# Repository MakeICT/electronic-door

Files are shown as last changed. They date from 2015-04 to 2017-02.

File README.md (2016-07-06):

# Master Control Program 

This system is used to secure spaces with an electronic door latch.

## Dependencies:
* [Node + NPM](Node.js)
* [PostgreSQL](http://www.postgresql.org/)
* [Arduino 1.6.5](https://www.arduino.cc/)

## Hardware requirements: 
* [Server protocol RS-485](https://en.wikipedia.org/wiki/RS-485) for the server/client communication.
* [Arduino Nano](https://www.arduino.cc/) for the door client (This is required for the matching footprint).
* [NFC reader](https://www.adafruit.com/products/364). This is the one that we are using for our version of the door lock. 

Diagram of the door lock project

* * *

## Todo
* Server
	* Super admins vs group admins
	* Make plugins respect disabled mode
	* When unlocking from web ui, display user in log
	
* Client
	* New NFC reader
	* Add doorbell input (capacitive?)
	* Design/build case for front
	* Build 2nd client for testing & back door

## License 

> Copyright (C) 2014-2016 MakeICT
> 
> This program is free software: you can redistribute it and/or modify it 
> under the terms of the GNU General Public License as published by the 
> Free Software Foundation, either version 3 of the License, or (at your 
> option) any later version.
> 
> This program is distributed in the hope that it will be useful, but 
> WITHOUT ANY WARRANTY; without even the implied warranty of 
> MERCHANTABILITY or FITNESS FOR A PARTICULAR PURPOSE.  See the GNU 
> General Public License for more details.
> 
> You should have received a copy of the GNU General Public License along 
> with this program.  If not, see [The GNU licenses page](http://www.gnu.org/licenses)
    
* * *

This is a work in progress. For more information, please visit the [MakeICT Wiki](http://makeict.org/wiki/index.php/Electronic_Door_Entry).

* * *

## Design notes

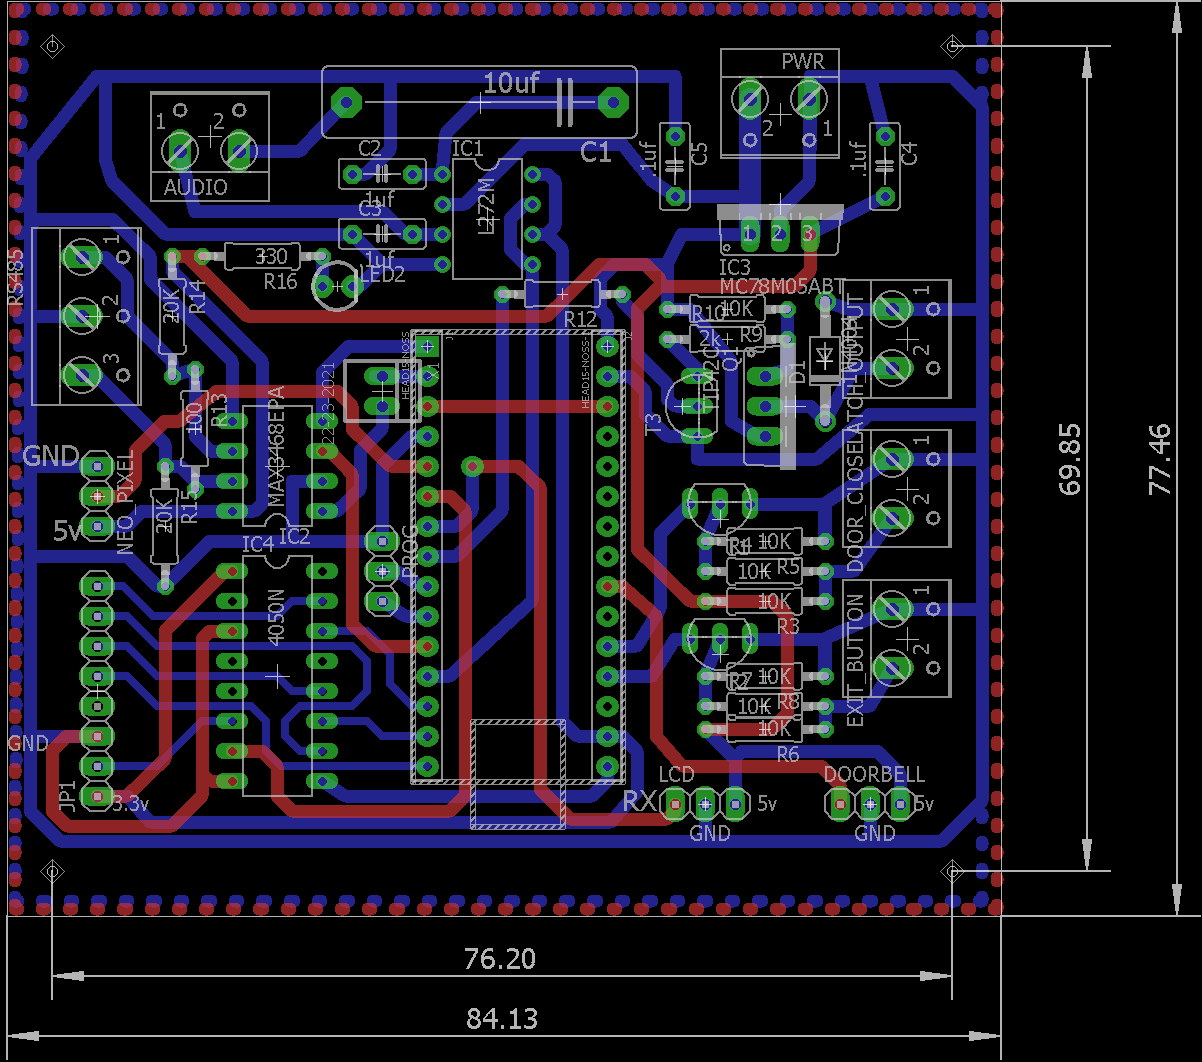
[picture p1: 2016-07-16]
door-client/hardware/doc/Door_Client_Layout_With_Dimensions.png

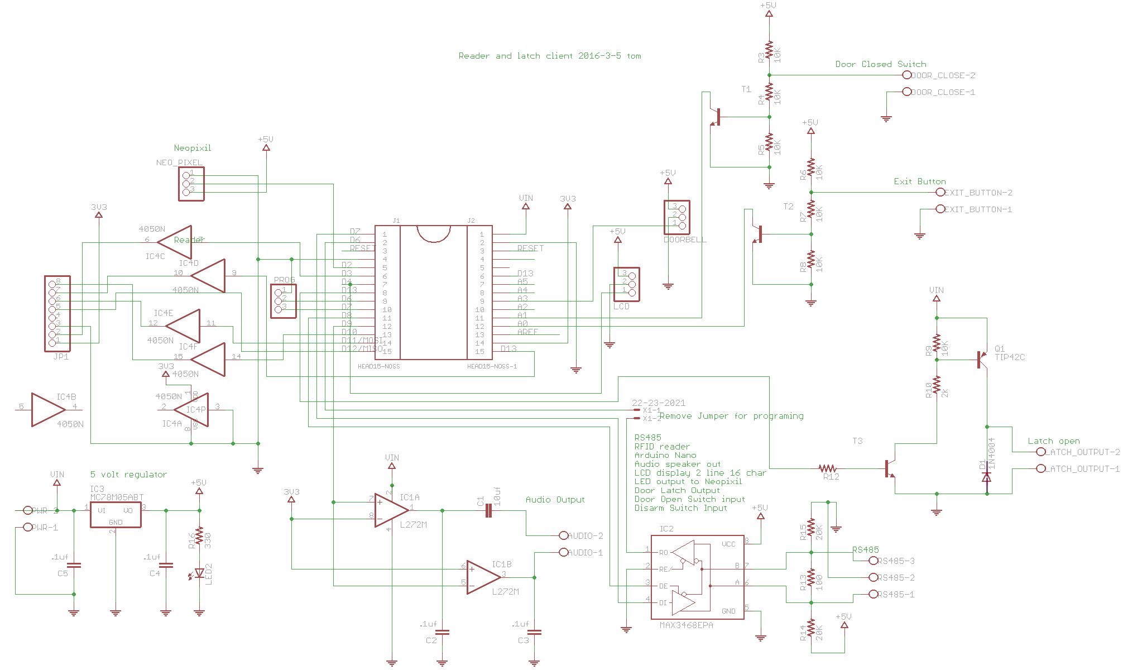
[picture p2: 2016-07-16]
door-client/hardware/doc/Door_Client_Schematic.png

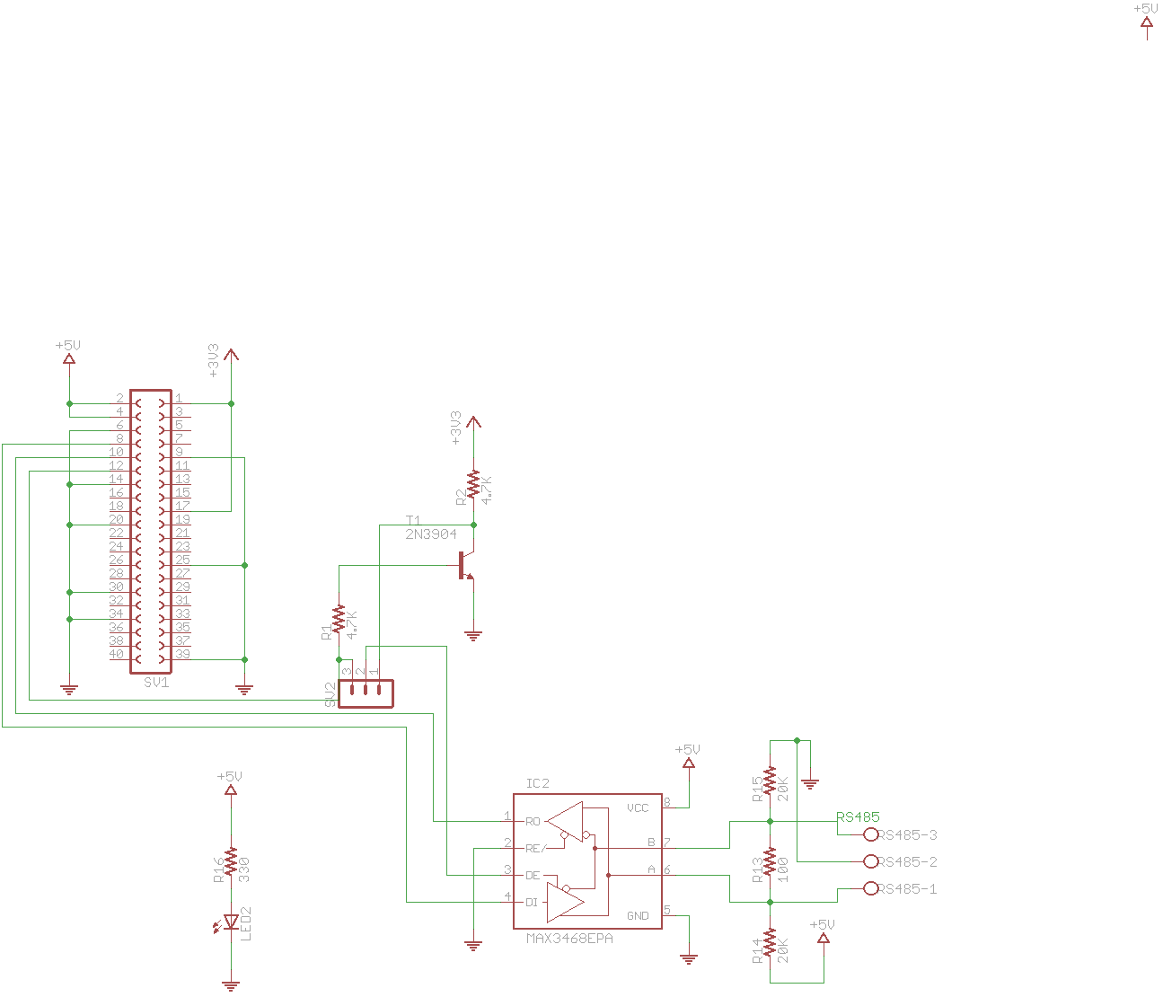
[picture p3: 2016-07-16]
server/hardware/doc/Server_Hat_Schematic.png

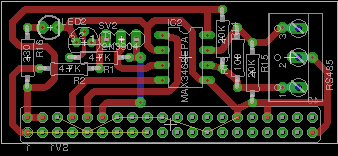
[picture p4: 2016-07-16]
server/hardware/doc/Server_Hat_Layout.png

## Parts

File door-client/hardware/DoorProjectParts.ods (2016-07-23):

 | DoorProject BOM |  |  |  |  | Total
 |  |  |  |  |  | $120.66
Item | Description | Part Number | Vendor | Qty | Cost | Extended | Total | alt | alt Tot | Vol Tot | STORE | Link | Alternate
2 | 63volts 10uF 5% | R60DN51005030J | Mouser | 1 | $2.50 | $2.50
3 | 0.5A Switching Reg | 580-7805SR-C | Mouser | 1 | $9.90 | $9.90
4 | TIP 32 PNP Epitaxial Sil | 512-TIP32 | Mouser | 1 | $0.45 | $0.45
5 | SF16 1A 400V Diode | 821-SF16 | Mouser | 1 | $0.26 | $0.26
6 | 2 x 16 STN-GRAY LCD | 763-0216B3ZFLGBW-V3 | Mouser | 1 | $20.00 | $20.00
7 | 14P TIN PIN TIN CONT | 575-199314 | Mouser | 3 | $0.46 | $1.38
8 | 2 Pos 5mm pitch | 651-1934861 | Mouser | 6 | $0.34 | $2.04
9 | 15W 12V 1.25A DC/DC | 709-SD15B-12 | Mouser | 1 | $15.50 | $15.50
10 | MAX485 IC | 700-MAX485CPA | Mouser | 1 | $2.60 | $2.60
11 | CD4050 IC | 595-CD4050BE | Mouser | 1 | $0.50 | $0.50
11 | NeoPixel Ring - 16 x WS2812 5050 RGB LED with Integrated | 16 x WS2812 5050 | Adafruit | 1 | $10.00 | $10.00
12 | PN532 NFC/RFID controller breakout board |  | Adafruit | 1 | $40.00 | $40.00
13 | Arduino Nano |  | ebay | 1 | $4.00 | $4.00
14 | 2n3904 npn transistor | 610-2N3904 | mouser | 3 | $0.51 | $1.53
15 | PCBoard | Custom | MakeICT | 1 | $10.00 | $10.00
 |  |  |  |  |  | $0.00
Item | Server components |  |  |  |  | Total
 |  |  |  |  |  | $96.30
1 | 24 Volt Power Supply, 6.5A, 150W, Switching, Hengfu POWER SUPPLY 1 |  | MPJA | 1 | $53.70 | $53.70
 | Raspberry Pi Model B+ | Products/1914 | Adafruit | 1 | $40.00 | $40.00
10 | MAX485 IC | 700-MAX485CPA | Mouser | 1 | $2.60 | $2.60

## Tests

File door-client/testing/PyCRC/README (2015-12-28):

PyCRC MODULES

----------------------
What is PyCRC?
----------------------

    This is an intended port to python for lib_crc library. It requires at least python 2.7.

----------------------
Version & Changelog
----------------------
    1.0 (oct 2011)    Initial launch

----------------------
How can it be used?
----------------------

    The CRC Modules are designed to be used separately (if you wanted for example to use
    only CRC16 you include only the specific file).

    Usage: 
        from CRCModules.CRC16SICK import CRC16SICK
        crcobj = CRC16SICK()
        res = crcobj.calculate("some string")
        print "{:10X}".format(res)

    Check provided pyCRC.py for a more detailed look.

----------------------
What CRC Modules are available?
----------------------

    CRC16           CRC16.py        for CRC16 and CRC16 Modbus
    CRC32           CRC32.py        for CRC32
    CRC16Kermit     CRC16Kermit.py  for CRC-CCITT (Kermit)
    CRC16SICK       CRC16SICK.py    for CRC16 (Sick)
    CRC16DNP        CRC16DNP.py     for CRC-DNP
    CRCCCITT        CRCCCITT.py     for CRC-CCITT (XModem), CRC-CCITT (0xFFFF) and CRC-CCITT (0x1D0F)

----------------------
Author
----------------------
    Cristian Năvălici (cristian.navalici@gmail.com)

----------------------
License
----------------------

    GNU GPLv3 as appear on http://www.gnu.org/licenses/gpl-3.0.txt

----------------------
Credits
----------------------
    go to Lammert Bies for his C Library (http://www.lammertbies.nl/download/lib_crc.zip)
    for online calculations (and more info): http://www.lammertbies.nl/comm/info/crc-calculation.html

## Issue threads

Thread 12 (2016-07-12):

Battery backup

Rowbotronics, 2016-07-12:
Implement hardware/software for battery backup.

Hardware: battery, charge circuitry, source switching

Software: reduce power usage when running on battery

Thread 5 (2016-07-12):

Change address without requiring reset

Rowbotronics, 2016-07-12:
Currently client has to be manually reset to change the address.  This makes it impossible to change addresses remotely.

Rowbotronics, 2016-08-03:
Address can now be changed via serial interface without resetting the client.

Closed 2016-08-03.

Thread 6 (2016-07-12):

Clients reboot frequently

Rowbotronics, 2016-07-12:
The microcontroller on the clients reboot fairly regularly.  Seems to be related to serial communication.

domstyle, 2016-07-13:
I think I narrowed this down a little bit - the clients are much more likely to reboot when processing an LCD command from the serial bus.

Rowbotronics, 2016-08-26:
Seems this issue was due to a hardware problem (insufficient power).  Adding an appropriate 3.3v regulator has nearly eliminated the issue.

atomicwire, 2016-08-26:
My bad. This has been a problem for a long time and hard to diagnose. I
feel bad that I didn't research the power requirements of the reader and
design the circuit better. I take it kind of hard cause I spent so many
years doing this very thing and I should really know better.

On Thu, Aug 25, 2016 at 7:49 PM, Rowbotronics <notifications@github.com>
wrote:

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

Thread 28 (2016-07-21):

Log when alarm button is pressed

Rowbotronics, 2016-07-21:
Would be nice to now if/when the alarm is being armed.

domstyle, 2016-07-22:
There should be messages in the log (as of just earlier today). A log message is generated when the arm or disarm command is sent to the alarm system, and another log message is generated when the system reports that it's armed status has changed.

Rowbotronics, 2016-07-22:
It looks like it only logs messages from the alarm decoder plugin, so there isn't any info about which client's button was pressed.  It would be good to know where the alarm got armed from.

domstyle, 2016-08-03:
It was logging when armed from the UI and not from clients, but now it should be logging both. It still doesn't log which client sent the arm message though.

domstyle, 2017-01-17:
Fixed

Closed 2017-01-17.

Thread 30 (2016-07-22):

Unknown clients shouldn't be able to arm the alarm system

Rowbotronics, 2016-07-22:
Accidentally deleted the client config for the front door, then the case fell open and hit the alarm button, arming the alarm.  Couldn't disable it from the front because the client was unknown, so I tried the back, but the server wasn't responding.  Loud noises happened, eventually restarted the server and got it disabled.

domstyle, 2016-08-03:
Code for the arming functionality should be moved to a plugin. This will prevent the server from processing newly-added clients (with no associated plugins) if they send arm messages.

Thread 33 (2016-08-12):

Temporary Key De-activation

Rowbotronics, 2016-08-12:
Currently, the only way to de-activate a key is to un-enroll it.  Once un-enrolled, it has to be re-scanned to enroll it again.  In the case of lost keys it would be nice to be able to temporarily de-activate the lost key, then re-activate it if found without requiring the key to be scanned again.

domstyle, 2016-08-12:
I've thought about this before and wondered if, when enrolling a key, we should show 2 lists: one of recent bad scans (what we currently show) and one of previously assigned keys specifically for that user.

I wonder if @poguepotamus has a preference.

Temporary de-activation exists already by just marking the whole account as inactive. Where it fails is that we have a nightly sync that will re-activate the account. We could correct that by adding a "do not sync" checkbox to each user or something.

poguepotamus, 2016-08-12:
I actually kinda like that Idea, I was thinking about that a few days ago, if someone was at the space when I wasn't there and had a key that they lost, I would just have to trust them to have the same key, scan it again, then continue using it. What if their was just a "lost" button, that woudl allow me to retrieve the key if they happened to find it again from say, the bottom of the unallowed key list, make it a different colour so the key-admin could tell.

domstyle, 2016-08-12:
@poguepotamus here are your options:

1. Allow keys to be marked as inactive, but keep them assigned to the user.
2. When enrolling a user, display their key assignment history, and allow a previous key to be reassigned
3. Allow users to be exempted from synchronization. This will allow us to mark users as inactive (which we can already do), so that their key won't work until they have been marked as active again.
4. Something else entirely.

Options 1 and 2 are probably the most user-obvious.
Option 2 provides the most flexibility ("I lost my 5th key, but I found my 2nd key. Can you activate that?").
Option 3 may be useful in other capacities.

poguepotamus, 2016-08-13:
I like both idea 2 and 3. But I have a few questions on number 3.
I have a feeling, even myself, will leave the checkmark checked. would
their be a way to see who all is being prevented from syncing, or a way to
email myself daily with the list. Some way to easily get the information.
Along with having the ability to not sync a particular person, would their
be the abilty to manually sync a particular person? Particularly, I can see
a use to sync someone right after I have unchecked the checkbox preventing
them from syncing.
Sorry for being so particular about this, but If were going to be using it,
I want it to be the best that it can be.

On Fri, Aug 12, 2016 at 1:33 PM Dominic Canare <notifications@github.com>
wrote:

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
--
Thanks for your time,
Matthew Pogue

Rowbotronics, 2016-08-18:
I think a combination of 1 & 2 would be the most useful in the long run.  Have a way to mark a users key as lost, which will de-activate it, but keep it associated with that user.  Maybe store it in a separate table with the user name attached so that it can be pulled up if needed.  Then we could check keys against this table and log if someone tries to get in with a key that has been lost.  Could be useful info.

I think 3 could be useful for other situations, but I don't think it would be a good idea to use that for lost keys.

poguepotamus, 2016-08-20:
I like that idea. If someone switches keys, I wont need easy access to it again, so setting it as lost and putting it in a different table would work great, allowing us to just reassign keys to people who have lost them.

I was coming to the same conclusion while thinking about it. Using it for lost keys just leaves too many opportunities for it to be left on for user errors. I like the idea of having it at some point, but when it does happen, I would like some type of notification to show who all is set to not sync. Even if its just a filter on the search.

domstyle, 2016-08-31:
Option 2 has been implemented. When enrolling a user, you will now see the 5 most recent rejections as well as that specific user's 5 most recent NFC assignments.

Closed 2016-08-31.

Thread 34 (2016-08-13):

[Solved][enhancements]

poguepotamus, 2016-08-13:
Just some very little things that can be changed to save seconds every time the program is used:

1. On the login screen, the cursor should default to the email box.
2. Hotkeys? I have ideas for hotkeys if its something that you guys are interested in doing. Just things to make it easier to get around the site.
3. Being able to tab through the site is currently the best way to get around on the keyboard (I like to stay on the keyboard), and I can't tab to the orange (activate) box to activate keys.
4. The plugins page is also un-tabable, making a little difficult to navigate there too.

poguepotamus, 2016-08-20:
I'm headed to bed now, Ill redo them tomorrow as separate issues and ill notify you to set it as solved.

poguepotamus, 2016-08-20:
Had some more time tonight. Go ahead and make this solved if you can. Thanks for the help.

Closed 2016-08-21.

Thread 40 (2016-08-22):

Key activating button error

poguepotamus, 2016-08-22:
When I give out a key, The key button, in which the key number is assigned, collapses when keys are assigned.

domstyle, 2016-08-30:
Fixed in the latest version. Should appear in production after the next restart.

Closed 2016-08-30.

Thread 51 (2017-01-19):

Add Log Pages

Rowbotronics, 2017-01-19:
Currently the log will only show a single page, so you can only see very recent events.  This can make the log pretty useless, especially since there is no filter yet.  It can fill up in a matter of hours (or minutes if you do a WildApricot sync).

Rowbotronics, 2019-03-03:
Log paging added in f2731a9ee290d0c800975af1f3440c4626fdf9e6

Closed 2019-03-03.

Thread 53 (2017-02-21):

Redirect to login page on session expiration

Rowbotronics, 2017-02-21:
Currently, when a login expires the server gives a "not logged in" error message, but leaves you in whatever page was previously loaded.

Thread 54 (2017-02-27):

Super Serial Watchdog Constantly Triggers

Rowbotronics, 2017-02-27:
The watchdog timer in the super serial code forces a reset any time the server does not receive an ACK response within a 60 second period.  This causes constant resets because the server is not regularly sending packets that require a response.

This is an issue because it fills up the log page (which has no filtering or pagination) rendering it fairly useless under many circumstances.

Related issues:
#51 Add Log Pages
#39 Add log filter options
#24 Make server send regular pings to clients

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

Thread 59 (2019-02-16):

API endpoints for clients

Rowbotronics, 2019-02-16:
We need to create API endpoints for network clients to replace the current serial interface.
* messages from new clients should create an unknown client entry on the clients page.
* clients should be able to send card info and receive an unlock or deny message in return
* client plugins should work in the same way as the current serial implementation

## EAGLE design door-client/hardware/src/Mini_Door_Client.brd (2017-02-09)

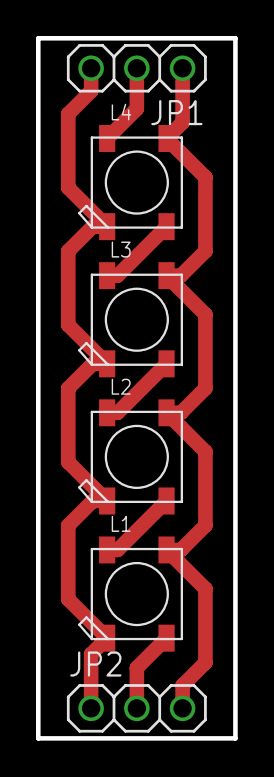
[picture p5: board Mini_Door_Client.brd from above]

Board: 2 copper layers, 11.0 x 38.9 mm, 6 parts (0 on the bottom side), 7 nets.

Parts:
JP1, JP2: 1X03
L1, L2, L3, L4: WS2812B

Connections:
+5V: JP1.1, JP2.3, L1.1-VDD, L2.1-VDD, L3.1-VDD, L4.1-VDD
GND: JP1.3, JP2.1, L1.3-GND, L2.3-GND, L3.3-GND, L4.3-GND
unnamed: L1.2-DOUT, L2.4-DIN
unnamed: L2.2-DOUT, L3.4-DIN
unnamed: L3.2-DOUT, L4.4-DIN
unnamed: JP1.2, L4.2-DOUT
unnamed: JP2.2, L1.4-DIN

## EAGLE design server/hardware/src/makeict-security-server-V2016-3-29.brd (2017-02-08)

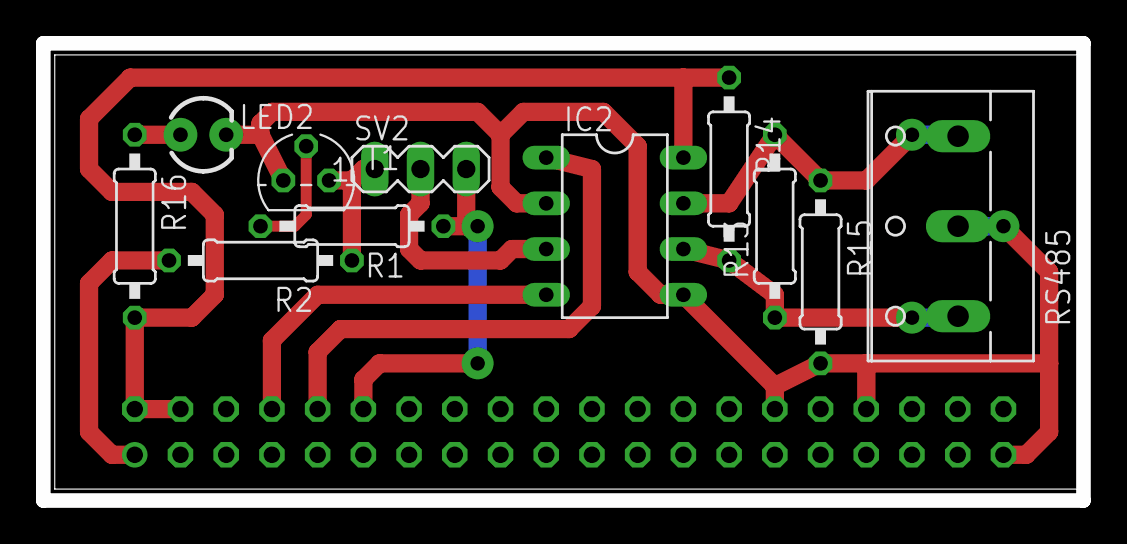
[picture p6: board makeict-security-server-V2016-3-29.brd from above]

Board: 2 copper layers, 57.8 x 25.4 mm, 12 parts (1 on the bottom side), 12 nets.

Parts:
IC2: MAX3468EPA; DIL08
LED2: LED3MM
R1, R2: 4.7K; 0207/10
R13: 100; 0207/10
R14, R15: 20K; 0207/10
R16: 330; 0207/10
RS485: W237-103
SV1: FE20-2
SV2: MA03-1
T1: 2N3904; TO92

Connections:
+3V3: R2.2, SV1.1, SV1.17
+5V: IC2.8, R14.1, R16.2, SV1.2, SV1.4
COM: IC2.2, IC2.5, LED2.K, R15.2, RS485.2, SV1.6, SV1.9, SV1.14, SV1.20, SV1.25, SV1.30, SV1.34, SV1.39, T1.3
D7: IC2.4, SV1.8
D8: IC2.3, SV2.2
unnamed: R1.1, SV1.12, SV2.3
unnamed: R1.2, T1.2
unnamed: R2.1, SV2.1, T1.1
unnamed: IC2.7, R13.2, R15.1, RS485.3
unnamed: IC2.6, R13.1, R14.2, RS485.1
unnamed: LED2.A, R16.1
unnamed: IC2.1, SV1.10

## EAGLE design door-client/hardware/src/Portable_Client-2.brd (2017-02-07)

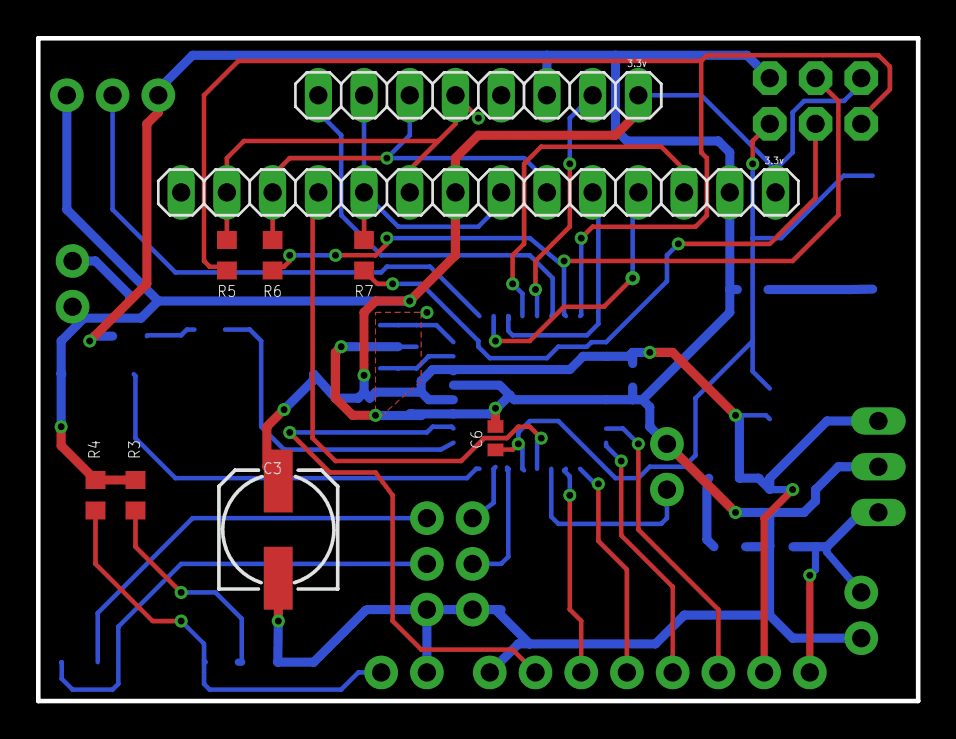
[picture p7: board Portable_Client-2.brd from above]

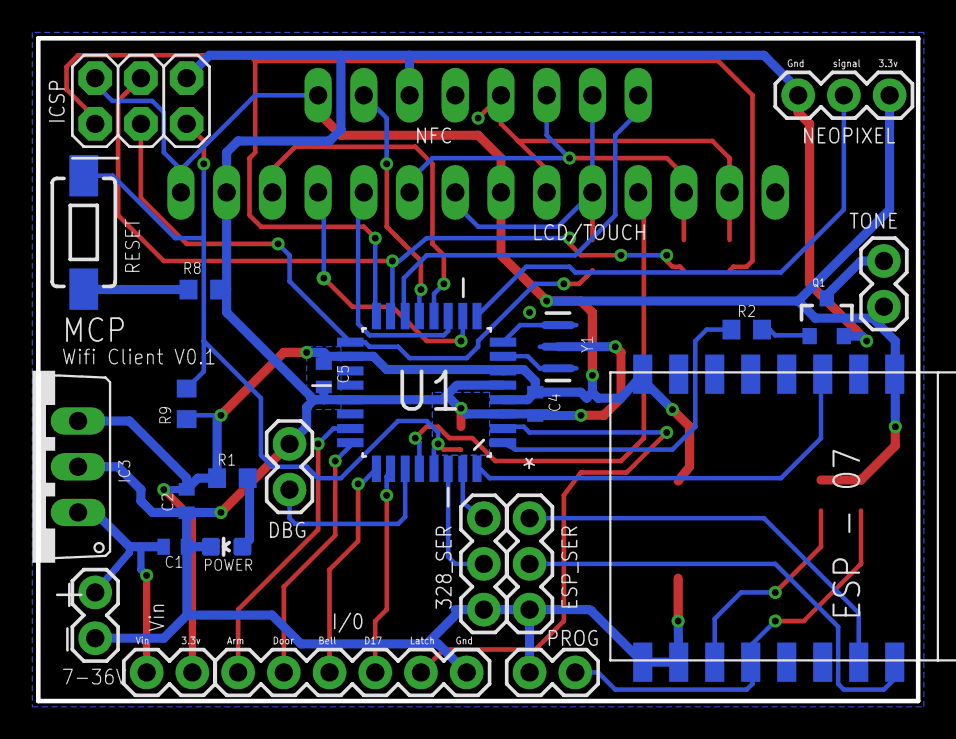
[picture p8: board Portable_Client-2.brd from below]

Board: 2 copper layers, 48.9 x 36.8 mm, 34 parts (25 on the bottom side), 37 nets.

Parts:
328_SER: 1X03
C1, C2: C0402
C3: 100uf; 153CLV-0605
C4, C5, C6: .1uf; C0402
DBG, DBG1: 1X02
ESP_SER: 1X03
I/0: 1X06
IC3: MC78M05ABT; TO220V
ICSP: 2X03
LCD/TOUCH: 1X14
NEOPIXEL: 1X03
NFC: 1X08
POW: 1X02
POWER: LED-0603
PROG: 1X02
Q1: SOT23-3
R1, R2, R5, R6, R7, R8: 330; R0603
R3, R4: 3.3k; R0603
R9: 4.7k; R0603
RESET: SWITCH-MOMENTARY-2SMD-1101NE; TACTILE-SWITCH-1101NE
TONE: 1X02
U1: ATMEGA328P-AU; QFP80P900X900X120-32N
U$2: ESP07-AITHINKER
Y1: 12MHZ; RESONATOR-SMD

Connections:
0SC2: U1.8, Y1.3
3V3: C2.1, C3.+, C4.1, C5.1, DBG1.2, IC3.3, ICSP.2, LCD/TOUCH.7, LCD/TOUCH.14, NEOPIXEL.1, NFC.1, R1.2, R3.1, R4.1, R9.1, TONE.1, U1.4, U1.6, U1.18, U$2.RESET1, U$2.VCC1
D0: 328_SER.2, U1.30
D1: 328_SER.3, U1.31
D2: U1.32, U$2.CH_PD1
D3: R2.2, U1.1
D4: I/0.2, U1.2
D5: NEOPIXEL.2, U1.9
D6: LCD/TOUCH.11, U1.10
D7: LCD/TOUCH.10, U1.11
D8: LCD/TOUCH.12, U1.12
D9: NFC.2, U1.13
D10: NFC.8, U1.14
D11: ICSP.4, R6.1, U1.15
D12: ICSP.1, R5.1, U1.16
D13: ICSP.3, R7.1, U1.17
D14: I/0.6, U1.23
D15: I/0.5, U1.24
D16: I/0.4, U1.25
D17: I/0.3, U1.26
D18: DBG.1, U1.27
D19: LCD/TOUCH.4, U1.28
ESP_RX: ESP_SER.3, U$2.RX1
ESP_TX: ESP_SER.2, U$2.TX1
GND: 328_SER.1, C1.2, C2.2, C3.-, C4.2, C5.2, C6.2, DBG.2, ESP_SER.1, I/0.1, IC3.2, ICSP.6, LCD/TOUCH.13, NEOPIXEL.3, NFC.3, POW.1, POWER.C, PROG.1, Q1.2, R8.1, U1.3, U1.5, U1.21, U$2.GND1, U$2.GPIO15, Y1.2
MISO: LCD/TOUCH.2, LCD/TOUCH.6, NFC.5, R5.2
MOSI: LCD/TOUCH.3, LCD/TOUCH.9, NFC.6, R6.2
unnamed: Q1.3, TONE.2
unnamed: Q1.1, R2.1
unnamed: R8.2, RESET.2
unnamed: PROG.2, R4.2, U$2.GPIO0
unnamed: R3.2, U$2.GPIO2
unnamed: POWER.A, R1.1
OSC1: U1.7, Y1.1
RESET: C6.1, ICSP.5, R9.2, RESET.1, U1.29
SCK: LCD/TOUCH.5, LCD/TOUCH.8, NFC.7, R7.2
VIN: C1.1, DBG1.1, IC3.1, POW.2

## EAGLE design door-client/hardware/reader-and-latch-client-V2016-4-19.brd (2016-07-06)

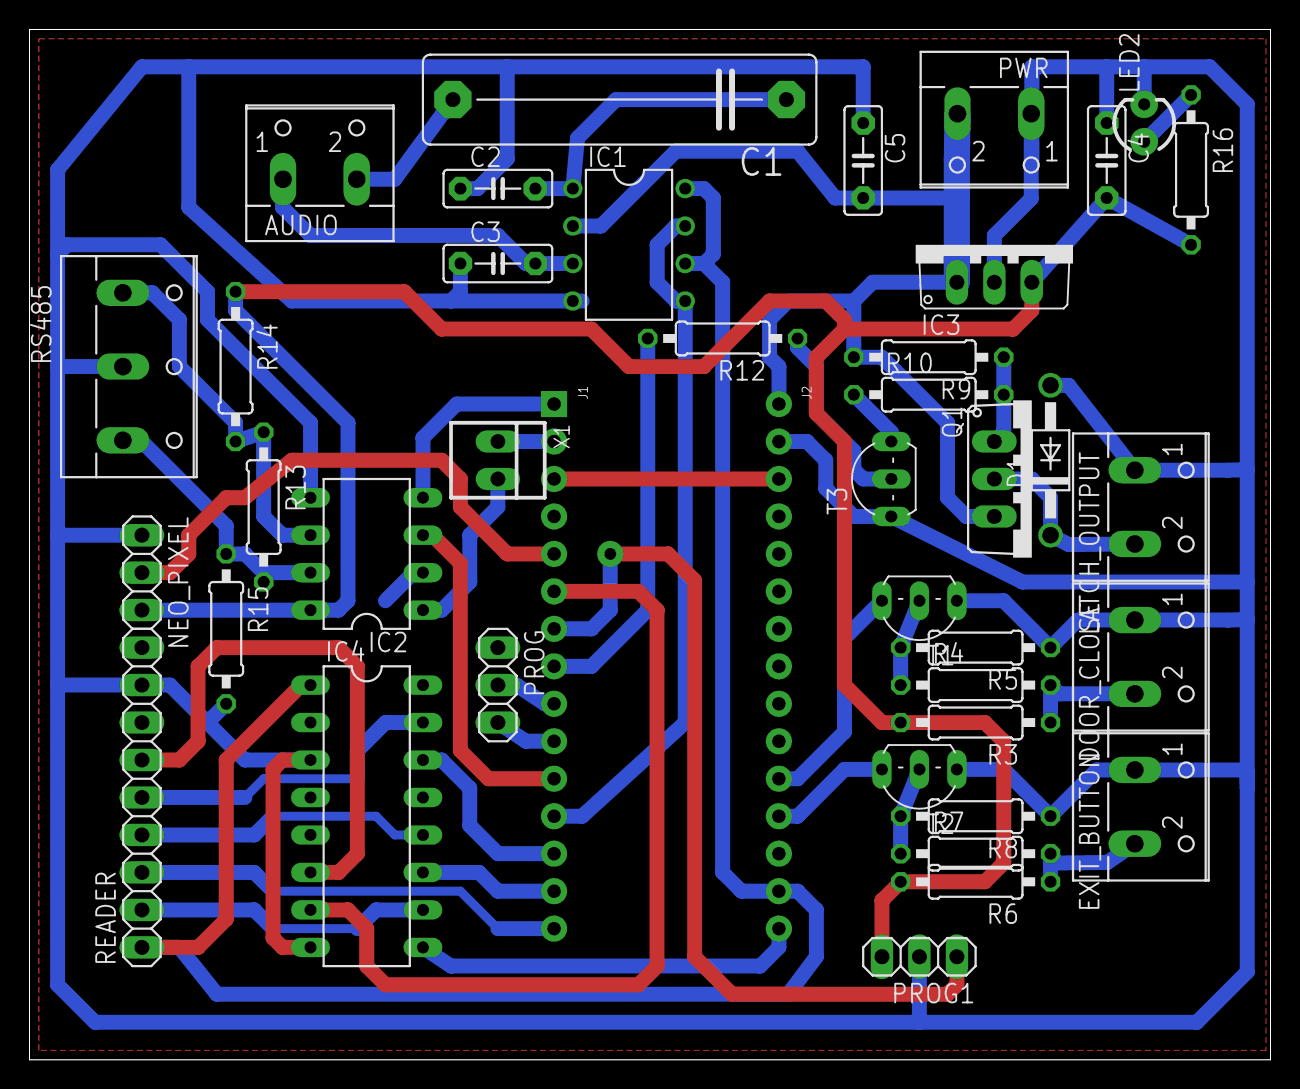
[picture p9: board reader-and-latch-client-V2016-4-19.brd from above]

Board: 2 copper layers, 84.1 x 69.8 mm, 41 parts (0 on the bottom side), 40 nets.

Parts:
AUDIO: W237-102
C1: 10uf; C22.5B6
C2, C3, C4, C5: .1uf; C5B2.5
D1: 1N4004; DO41-10
DOOR_CLOSE: W237-102
EXIT_BUTTON: W237-102
IC1: L272M; DIL08
IC2: MAX3468EPA; DIL08
IC3: MC78M05ABT; TO220V
IC4: 4050N; DIL16
J1: HEAD15-NOSS
J2: HEAD15-NOSS-1
LATCH_OUTPUT: W237-102
LED2: LED3MM
NEO_PIXEL: 1X03
PROG, PROG1: 1X03
PWR: W237-102
Q1: TIP42C; TO220AV
R3, R4, R5, R6, R7, R8, R9: 10K; 0207/10
R10: 2k; 0207/10
R12: 0207/10
R13: 100; 0207/10
R14, R15: 20K; 0207/10
R16: 330; 0207/10
READER: 1X09
RS485: W237-103
T1, T2, T3: TO92-EBC
X1: 22-23-2021

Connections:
3V3: IC1.6, IC1.8, IC4.1, J2.14, READER.1
+5V: C4.2, IC2.8, IC3.3, NEO_PIXEL.3, PROG1.3, R3.2, R6.2, R14.1, R16.2
A0: J2.12, T2.C
A1: J2.11, T1.C
COM: C2.1, C3.1, C4.1, C5.1, D1.A, DOOR_CLOSE.1, EXIT_BUTTON.1, IC1.4, IC2.2, IC2.5, IC3.2, IC4.3, IC4.8, J1.4, J2.2, LATCH_OUTPUT.1, LED2.K, NEO_PIXEL.1, PROG.1, PROG1.2, PWR.1, R5.1, R8.1, R15.2, READER.8, RS485.2, T1.E, T2.E, T3.E
D2: J1.5, NEO_PIXEL.2
D3: IC4.7, J1.6
D4: J1.7, PROG1.1
D6: J1.2, X1.1
D7: IC2.4, J1.1
D8: IC2.3, J1.11
D9: IC1.5, IC1.7, J1.12
D10: IC4.14, J1.13
D11/MOSI: IC4.11, J1.14
D12/MISO: J1.15, READER.3
D13: J1.8, R12.2
unnamed: D1.C, LATCH_OUTPUT.2, Q1.C
unnamed: R12.1, T3.B
unnamed: IC4.6, READER.6
unnamed: IC2.7, R13.2, R15.1, RS485.3
unnamed: IC2.6, R13.1, R14.2, RS485.1
unnamed: J1.9, PROG.2
unnamed: C1.1, C2.2, IC1.1
unnamed: AUDIO.2, C1.2
unnamed: AUDIO.1, C3.2, IC1.3
unnamed: LED2.A, R16.1
unnamed: R4.1, R5.2, T1.B
unnamed: DOOR_CLOSE.2, R3.1, R4.2
unnamed: R7.1, R8.2, T2.B
unnamed: EXIT_BUTTON.2, R6.1, R7.2
unnamed: R10.1, T3.C
unnamed: Q1.B, R9.1, R10.2
unnamed: IC4.10, READER.2
unnamed: IC4.12, READER.4
unnamed: IC4.15, READER.5
unnamed: J1.10, PROG.3
unnamed: IC4.9, J2.15
unnamed: IC2.1, X1.2
RESET: J1.3, J2.3
VIN: C5.2, IC1.2, IC3.1, J2.1, PWR.2, Q1.E, R9.2

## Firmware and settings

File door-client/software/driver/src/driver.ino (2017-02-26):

/*-----( Include needed libraries )-----*/
#include <avr/wdt.h>
#include <Arduino.h>
#include <SoftwareSerial.h>
//#include <SPI.h>
//#include <LiquidCrystal.h>
//#include <Adafruit_NeoPixel.h>
//#include <EEPROM.h>
//#include <PN532_SPI.h>
//#include <MFRC522.h>    //TODO: only include if necessary
//#include "PN532Interface.h"




/*-----( Include project files )-----*/
#include "packetqueue.h"
#include "ring.h"
#include "reader.h"
#include "rs485.h"
#include "lcd.h"
#include "audio.h"
#include "strike.h"
#include "config.h"
#include "superserial.h"
#include "utils.h"

/*-----( Declare Constants and Pin Numbers )-----*/

// Constants for machine states
#define S_INITIALIZING      0
#define S_NO_SERVER         1
#define S_UNADDRESSED       2
#define S_WAIT_SEND         3
#define S_READY             4


/*-----( Declare objects )-----*/
Reader card_reader;
rs485 bus(SSerialTxControl);
//SuperSerial* superSerial;
//TEMPORARY TEST CODE

Ring statusRing(RING_PIN, NUMPIXELS);
//LCD readout;
Audio speaker(SPEAKER_PIN);
Strike doorLatch(LATCH_PIN);
Config conf;

uint8_t address = ADDR_CLIENT_DEFAULT;     //@TODO: this shouldn't be necessary
SuperSerial superSerial(&bus, address);

/*-----( Declare Variables )-----*/
//uint8_t byteReceived;
boolean alarmButton = 0;
#ifdef MOD_DOOR_SWITCH
boolean doorState = 0;
#else
boolean doorState = 1;
#endif
boolean doorBell = 1;
uint32_t lastIDSend = 0;
uint32_t lastHeartBeat = 0;

//byte userTune[USER_TUNE_LENGTH];
//byte userTuneDurations[USER_TUNE_LENGTH];
byte state = S_INITIALIZING;

/*-----( Declare Functions )-----*/
uint8_t* nfc_poll();
void CheckReader();
void CheckInputs();
void ProcessMessage();

SoftwareSerial dbgPort(6,7);
SoftwareSerial* debugPort = &dbgPort;

LCD readout;

void setup(void) {
  // Initialize debug port and pass references
  watchdogSetup();
  dbgPort.begin(57600);
  superSerial.SetDebugPort(debugPort);
  bus.SetDebugPort(debugPort);
  card_reader.SetDebugPort(debugPort);
  conf.SetDebugPort(debugPort);
  speaker.SetDebugPort(debugPort);
  conf.Init();

  Serial.begin(9600);   //@TODO:  What is this doing here?
  LOG_INFO(F("\r\n\r\n"));
  LOG_INFO(F("########################################\r\n"));
  LOG_INFO(F("#            Start Program             #\r\n"));
  LOG_INFO(F("########################################\r\n"));


  // Set input pins
  pinMode(DOOR_SWITCH_PIN, INPUT_PULLUP);
  pinMode(ALARM_BUTTON_PIN, INPUT_PULLUP);
  pinMode(DOOR_BELL_PIN, INPUT_PULLUP);
  //pinMode(LCD_SERIAL_TX, OUTPUT);

  #ifdef MOD_DOOR_SWITCH
  doorState = digitalRead(DOOR_SWITCH_PIN);
  #endif

 // superSerial = new SuperSerial(&bus, address);

  doorLatch.Lock();  // In case the program crashed, make sure door doesn't stay unlocked

  //for testing only
  #ifdef CLIENT_ADDRESS
  conf.SetAddress(CLIENT_ADDRESS);
  conf.SaveCurrentConfig();
  #endif

  address = conf.GetAddress();
  superSerial.SetAddress(address);

  LOG_INFO(F("Address: "));
  LOG_INFO(address);
  LOG_INFO(F("\r\n"));
  readout.Print("Initializing...");

  #ifdef MOD_NFC_READER
  if(!card_reader.start())  {
    statusRing.SetMode(conf.GetErrorLightSequence());
    readout.Print("NFC Reader      not detected!");
  }
  else
  #endif
  {
    statusRing.SetMode(conf.GetDefaultLightSequence());
    speaker.Play(conf.GetStartTune());
    state = S_READY;
  }

  // notify server that client has started
  superSerial.QueueMessage(F_CLIENT_START, 0, 0);

}


void loop(void) {
  static uint8_t limit = 0;
  if (limit++ == 0)
    LOG_DEBUG(F("."));
  wdt_reset();
  LOG_DUMP(F("Free RAM: "));
  LOG_DUMP(freeRam());
  LOG_DUMP (F("\r\n"));
  static uint8_t lastState = 10;
  if (state != lastState)  {
    lastState = state;
    LOG_INFO(F("State changed to: "));
    LOG_INFO(state);
    LOG_INFO(F("\r\n"));
  }
  static uint32_t lastRead = 0;
  uint32_t currentMillis = millis();
  switch(state)
  {
    case S_READY:
    {
      #ifdef MOD_NFC_READER
      if ((currentMillis - lastRead ) > NFC_READ_INTERVAL &&
          (currentMillis - lastIDSend) > ID_SEND_INTERVAL)  {
        CheckReader();
        lastRead = currentMillis;
      }
      #endif
      CheckInputs();
    }

    case S_WAIT_SEND:
    {
      if (!doorState && !doorLatch.HoldingOpen() && !doorLatch.Locked())  {
        LOG_DEBUG(F("Door opened, re-latching\r\n"));
        doorLatch.Lock();
      }
      if (currentMillis - lastHeartBeat > HEARTBEAT_TIMEOUT)  {
        //Set LEDS and LCD to indicate loss of communication
        LOG_ERROR(F("Lost contact with server!\r\n"));
        readout.Print("  Lost Contact    With  Server  ");
        statusRing.SetMode(conf.GetErrorLightSequence());
        state = S_NO_SERVER;
        break;
      }
    }

    case S_UNADDRESSED:
    {
      superSerial.Update();
      if (!superSerial.DataQueued()) {
        state = S_READY;
      }
    }

    case S_NO_SERVER:
    {
      if (state == S_NO_SERVER)  {
        superSerial.Update();
      }
      if (superSerial.NewMessage())  {
        if (state == S_NO_SERVER)  {
          LOG_DEBUG(F("Contact with server re-established\r\n"));
          //reset lights to idle
          statusRing.SetMode(conf.GetDefaultLightSequence());
          superSerial.QueueMessage(F_CLIENT_START, 0, 0);
        }
        state = S_WAIT_SEND;
        ProcessMessage();
      }
    }

    case S_INITIALIZING:
    {
      speaker.Update();
      statusRing.Update();
      doorLatch.Update();
    }
  }
}

void CheckReader()  {
  LOG_DUMP(F("Checking NFC Reader\r\n"));
  //check for NFC card
  static uint8_t lastuid[7] = {0};
  uint8_t uid[7] = {0};
  uint8_t id_length;
  bool sameID = true;
  static uint8_t readFailures = 0;

  uint8_t result = card_reader.poll(uid, &id_length);
  while (result == 2)  {
    if (++readFailures > 2)  {
      LOG_DEBUG(F("NFC read failed 3 times.  Commiting suicide.\r\n"));
      while(1);   //hang program and force watchdog reset; (this is probably not the best thing)
    }
    result = card_reader.poll(uid, &id_length);
  }

  readFailures = 0;   //reset failure counter on successful read
  if (result == 1)  {
    for (int i = 0; i < 7; i++)  {
      if (uid[i] != lastuid[i]){
        sameID = false;
        break;
      }
    }
    #if LOG_LVL>2
    LOG_INFO(F("Scanned ID: "));
    for(int i=0; i<7; i++)  {
      LOG_INFO(uid[i]);
      LOG_INFO(F(" "));
    }
    LOG_INFO(F("\r\n"));
    #endif
    if (!sameID || millis() - lastIDSend > SAME_ID_SEND_INTERVAL) {
      superSerial.QueueMessage(F_SEND_ID, uid, 7);
      state = S_WAIT_SEND;
      lastIDSend = millis();
      statusRing.SetMode(conf.GetWaitLightSequence());
      arrayCopy(uid, lastuid, 7, 0);
      LOG_DUMP(F("Sending scanned ID.\r\n"));
    }
    else  {
      LOG_DEBUG(F("Not re-sending same ID more than once in configured timeout.\r\n"));
    }
  }
  else  {
    //Do nothing if no new card read
  }
}

void ProcessMessage()  {
  Message msg = superSerial.GetMessage();

  //reset heartbeat timeout
  lastHeartBeat = millis();

  // If address is not set, ignore all functions other than setting address
  if (state == S_UNADDRESSED && msg.function != F_SET_CONFIG)  {
    return;
  }
  //Process functions
  LOG_INFO(F("Got Message: "));
  switch(msg.function)
  {
    case F_HEARTBEAT:
      LOG_INFO(F("Heartbeat Ping\r\n"));

    case F_SET_CONFIG:
      LOG_INFO(F("Set Config:"));
      switch(msg.payload[0])
      {
        case 0x00:
        LOG_INFO(F("Address:"));
        LOG_INFO(msg.payload[1]);
        LOG_INFO(F("\r\n"));
        conf.SetAddress(msg.payload[1]);
        conf.SaveCurrentConfig();
        superSerial.SetAddress(msg.payload[1]);
        break;

        case 0x01:
        {
          LOG_INFO(F("Start Tune\r\n"));
          uint8_t tune_length = (msg.length-1)/2;
          struct tune temp = {.length = tune_length};
          for(uint8_t i = 0; i < tune_length; i++)  {
            temp.notes[i] = msg.payload[i+1];
            temp.durations[i] = msg.payload[i+1 + tune_length];
          }
          conf.SetStartTune(temp);
          conf.SaveCurrentConfig();
        }
        break;

        case 0x0A:
        case 0x0B:
        case 0x0C:
        case 0x0D:
        case 0x0E:
        {
          struct lightMode newMode =  {msg.payload[1],
                                      COLOR(msg.payload[2],msg.payload[3],msg.payload[4]),
                                      COLOR(msg.payload[5],msg.payload[6],msg.payload[7]),
                                     (msg.payload[8]<<8) + msg.payload[9], (msg.payload[10]<<8)+msg.payload[11]};

          if (msg.payload[0] == 0x0A)  {
            LOG_INFO(F("Default Light Pattern\r\n"));
            conf.SetDefaultLightSequence(newMode);
          }
          if (msg.payload[0] == 0x0B)  {
            LOG_INFO(F("Wait Light Pattern\r\n"));
            conf.SetWaitLightSequence(newMode);
          }
          else if (msg.payload[0] == 0x0C)  {
            LOG_INFO(F("Error Light Pattern\r\n"));
            conf.SetErrorLightSequence(newMode);
          }
          else if (msg.payload[0] == 0x0D)  {
            LOG_INFO(F("Unlock Light Pattern\r\n"));
            conf.SetUnlockLightSequence(newMode);
          }
          else if (msg.payload[0] == 0x0E)  {
            LOG_INFO(F("Deny Light Pattern\r\n"));
            conf.SetDenyLightSequence(newMode);
          }
          conf.SaveCurrentConfig();
          break;
        }
        default:
          LOG_INFO(F("Invalid configuration identifier\r\n"));
          break;
      }
      //state = S_READY;
      break;

    case F_DENY_CARD:
      LOG_INFO(F("Card Denied\r\n"));
      statusRing.SetMode(conf.GetDenyLightSequence());
      break;

    case F_UNLOCK_DOOR:
      LOG_INFO(F("Unlock Door\r\n"));
      if (doorState)  {
        LOG_DEBUG(F("Unlocking for "));
        LOG_DEBUG((msg.payload[0] << 8) + msg.payload[1]);
        LOG_DEBUG(F(" seconds.\r\n"));
        doorLatch.Unlock(((msg.payload[0] << 8) + msg.payload[1]));
      }
      else  {
        LOG_DEBUG(F("Door Open, so not unlatching\r\n"));
      }
      statusRing.SetMode(conf.GetUnlockLightSequence());
      break;

    case F_LOCK_DOOR:
      LOG_INFO(F("Lock Door\r\n"));
      doorLatch.Lock();
      break;

    case F_PLAY_TUNE:
    {
      LOG_INFO(F("Play Tune\r\n"));
      byte tune_length = (msg.length)/2;
      uint8_t userTune[tune_length];
      uint8_t userTuneDurations[tune_length];
      for(byte i = 0; i < tune_length; i++)  {
        userTune[i] = msg.payload[i];
        userTuneDurations[i] = msg.payload[i + tune_length];
      }
      speaker.Play(userTune, userTuneDurations, tune_length);
      break;
    }
    case F_SET_LIGHTS:
    {
      LOG_INFO(F("Set Lights\r\n"));
      statusRing.SetMode(msg.payload[0],
                          COLOR(msg.payload[1],msg.payload[2],msg.payload[3]),
                          COLOR(msg.payload[4],msg.payload[5],msg.payload[6]),
                         (msg.payload[7]<<8) + msg.payload[8], (msg.payload[9]<<8)+msg.payload[10]);
      break;
    }
    case F_SET_LCD:
    {
      LOG_INFO(F("Set LCD\r\n"));
      char printString[msg.length + 1];
      arrayCopy(msg.payload, (byte*) printString, msg.length);
      printString[msg.length+1] = '\0';
      readout.Print(printString);
      break;
    }

    default:
      LOG_WARNING(F("Unrecognized Command: "));
      LOG_WARNING(msg.function);
      LOG_WARNING(F("\r\n"));
  }
}

void CheckInputs()  {
  if(digitalRead(ALARM_BUTTON_PIN) != alarmButton)  {
    alarmButton = !alarmButton;
    if (alarmButton == 1)  {
      LOG_INFO(F("Arm Alarm Button Pressed\r\n"));
      byte payload[1] = {alarmButton};
      superSerial.QueueMessage(F_ALARM_BUTTON, payload, 1);
      state = S_WAIT_SEND;
    }
    return;
  }

  #ifdef MOD_DOOR_SWITCH
  if(digitalRead(DOOR_SWITCH_PIN) != doorState)  {
    LOG_INFO(F("Door State Changed\r\n"));
    doorState = !doorState;
    byte payload[1] = {doorState};
    superSerial.QueueMessage(F_DOOR_STATE, payload, 1);
    state = S_WAIT_SEND;
    return;
  }
  #endif

  #ifdef MOD_DOORBELL
  if(digitalRead(DOOR_BELL_PIN) != doorBell)  {
    doorBell = !doorBell;
    if (doorBell == 1)  {
      LOG_INFO(F("Door Bell Pressed\r\n"));
      byte payload[1] = {doorBell};
      superSerial.QueueMessage(F_DOOR_BELL, payload, 1);
      state = S_WAIT_SEND;

      //Temporary hard-coded doorbell
      struct tune testA = {26, {0x35,0x00,0x35,0x00,0x35,0x00,0x31,0x00,0x35,0x00,0x38,0x00,0x20},
                               {0x06,0x01,0x06,0x06,0x06,0x06,0x06,0x01,0x06,0x06,0x0b,0x11,0x0b}};
      struct lightMode testL = {M_FLASH, COLOR(120,0,120), COLOR(120,120,120), 200, 3000};
      readout.Print("    You rang?                   ");
      speaker.Play(testA);
      statusRing.SetMode(testL);

    }
    return;
  }
  #endif
}

void watchdogSetup(void)
{
  cli();       // disable all interrupts
  wdt_reset(); // reset the WDT timer
  /*
   WDTCSR configuration:
   WDIE = 0 :Interrupt Enable
   WDE  = 1 :Reset Enable
   WDP3 = 1 :For 8000ms Time-out
   WDP2 = 0 :For 8000ms Time-out
   WDP1 = 0 :For 8000ms Time-out
   WDP0 = 1 :For 8000ms Time-out
  */
  // Enter Watchdog Configuration mode:
  WDTCSR |= (1<<WDCE) | (1<<WDE);
  // Set Watchdog settings:
  WDTCSR = (0<<WDIE) | (1<<WDE) | (1<<WDP3) | (0<<WDP2) | (0<<WDP1) | (1<<WDP0);
  sei();
}

ISR(WDT_vect) // Watchdog timer interrupt.
{
  //Put any future freeze debugging code here
}

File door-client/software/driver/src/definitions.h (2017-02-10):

// Module selection
#define MOD_SERIAL
#define MOD_LIGHT_RING
#define MOD_LATCH
#define MOD_ALARM_BUTTON
#define MOD_DOOR_SWITCH
#define MOD_NFC_READER
#define MOD_DOORBELL
#define MOD_CHIME
#define MOD_LCD

// Pin assignments
#define RS485_RX          0       // Reserved for hardware serial
#define RS485_TX          1       // Reserved for hardware serial
#define RING_PIN          2       // Pin communicating with NeoPixel Ring
#define NFC_RESET_PIN     3       // Pin to reset RC522 NFC module
#define LCD_SERIAL_TX     4       // Serial data for LCD
#define LATCH_PIN         5       // Digital pin to trigger door strike circuit
#define SSerialRX         6       // Debug Serial Receive pin (Not used)
#define SSerialTX         7       // Debug Serial Transmit pin
#define SSerialTxControl  8       // RS485 Direction control
#define SPEAKER_PIN       9       // Tone generation pin
#define NFC_CS_PIN        10      // SPI Slave Select pin
#define NFC_SPI_1         11      // Reserved for hardware SPI for NFC reader
#define NFC_SPI_2         12      // Reserved for hardware SPI for NFC reader
#define NFC_SPI_3         13      // Reserved for hardware SPI for NFC reader
#define ALARM_BUTTON_PIN  14      // Big button to arm the alarm
#define DOOR_SWITCH_PIN   15      // Magnetic switch on door
#define LCD_SERIAL_RX     16      // Not actually connected but need pin assigned for now
#define DOOR_BELL_PIN     17      // Door bell pin

//Set log level
#define LOG_LVL 0

//Force client address
#define CLIENT_ADDRESS 0x09

// NFC Reader selection
//#define READER_RC522
#define READER_PN532

// Constants for audio playback
#define USER_TUNE_LENGTH    30      // Max number of notes in entry melody

// Constants for PN532 NFC reader
#define NFC_READ_INTERVAL     100     // time in ms between NFC reads
#define ID_SEND_INTERVAL      1000    // time in ms between sending card IDs
#define SAME_ID_SEND_INTERVAL 5000    // time in ms between re-sending same card ID

// Constants for NeoPixel ring
#define NUMPIXELS           16      // Number of NeoPixels in Ring

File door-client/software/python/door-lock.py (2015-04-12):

#!/usr/bin/python
# -*- coding: utf-8 -*-
'''
MakeICT/Bluebird Arthouse Electronic Door Entry

door-lock.py: unlocks the door on a succesful NFC read

Authors:
	Dominic Canare <dom@greenlightgo.org>
	Rye Kennedy <ryekennedy@gmail.com>
	Christian Kindel <iceman81292@gmail.com>
'''

import os, time, sys, signal, subprocess, logging, logging.config, yaml

from backend import backend
from rpi import interfaceControl

Dir = os.path.realpath(os.path.dirname(__file__))
config = os.path.join(Dir, 'config.yml')
global_config = yaml.load(file(config, 'r'))

lastDoorStatus = [0,0]
logging.config.dictConfig(global_config['logging'])
log=logging.getLogger('door-lock')

log.info("==========[door-lock.py started]==========")
def signal_term_handler(sig, frame):
	log.info("Received SIGTERM")
	cleanup()
signal.signal(signal.SIGTERM, signal_term_handler)

def cleanup():
	log.info("Cleaning up and exiting")
	interfaceControl.cleanup()
	if interfaceControl.PN532:
		process = subprocess.Popen(['pidof', 'nfc-poll'], stdout=subprocess.PIPE)
		out, err = process.communicate()
		if out != '':
			os.kill(int(out), signal.SIGTERM)
	sys.exit(0)

def checkDoors():
	global lastDoorStatus
	currentDoorStatus = interfaceControl.checkDoors()

	if currentDoorStatus[0] > lastDoorStatus[0]:
		log.info("Door 1: OPEN")
	elif currentDoorStatus[0] < lastDoorStatus[0]:
		log.info("Door 1: CLOSED")
		proc = subprocess.Popen(['/home/pi/code/makeictelectronicdoor/vista/arm-away.sh'], stdout=subprocess.PIPE)
		proc.communicate()
		log.info("Arm Away sent")
	if currentDoorStatus[1] > lastDoorStatus[1]:
		log.info("Door 2: OPEN")
	elif currentDoorStatus[1] < lastDoorStatus[1]:
		log.info("Door 2: CLOSED")

	lastDoorStatus = currentDoorStatus

def checkCards():
#	log.debug("Starting NFC read")
	nfcID = interfaceControl.nfcGetUID()
#	log.debug("Finished NFC read")
	#interfaceControl.setPowerStatus(False)

	if nfcID != None:
		log.info("Scanned card ID: %s" % nfcID)
		user = backend.getUserByKeyID(nfcID)	
		if user != None:
			if user['status'] == 'active':
				log.info("ACCEPTED card ID: %s" % nfcID)
				log.info("Access granted to '%s %s'" % (user['firstName'], user['lastName']))
				backend.log('unlock', nfcID, user['userID'])
				log.info("Door 1: UNLOCKED")
				interfaceControl.unlockDoor()
				proc = subprocess.Popen(['/home/pi/code/makeictelectronicdoor/vista/disarm.sh'], stdout=subprocess.PIPE)
				proc.communicate()
				log.info("Door 1: LOCKED")
			else:
				log.warning("DENIED card  ID: %s" % nfcID)
				log.warning("Reason: '%s %s' is not active" % (user['firstName'], user['lastName']))
				backend.log('deny', nfcID, user['userID'])
				interfaceControl.showBadCardRead()
		else:
			log.warning("DENIED card  ID: %s" % nfcID)
			log.warning("Reason: card not registered")
			backend.log('deny', nfcID)
			interfaceControl.showBadCardRead()

log.debug("Entering monitor loop")
interfaceControl.setPowerStatus(True)
while True:
	try:
		checkDoors()
		checkCards()
		time.sleep(0)

	except KeyboardInterrupt:
		log.info("Received KeyboardInterrupt")
		interfaceControl.setPowerStatus(False)
		cleanup()

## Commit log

2014-07-24 Added code for monitoring door state (untested) -activated internal pull-ups on switch inputs in rpi.py -added method to return door state in rpi.py -added code to check door state and print changes 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
2014-07-24 Fixed typos and tested door switch code. -Made some changes for testing. These should be removed before submitting pull request
    [door-lock.py, rpi.py]
2014-07-25 Added code for buzzer PWM -added both hardware and software PWM code -hardware PWM is currently active, required changing buzzer from pin 10 to pin 18 -software pwm was choppy
    [door-lock.py, rpi.py]
2014-07-25 Fix whitespace in door-lock.py, adjust hardware PWM tone
    [door-lock.py, rpi.py]
2014-07-25 Removed software PWM code
2014-07-25 Remove hardware PWM code
2014-07-25 Remove all PWM code, fix indent error in door-lock.py -PWM code now in 2 seperate branches -incorrect indent broke door status printing
    [door-lock.py, rpi.py]
2014-07-25 Remove leftover line of PWM code, change some test code
2014-07-27 Add code to set hardware PWM mode
2014-08-01 Remove references to wiringpi2, change software PWM frequency
2014-08-01 Fix string formatting in card read logs
    [door-lock.py]
2014-08-01 Tweak log outputs and temporary fix for log file paths -absolute file paths should be replaced
    [door-lock.py, enroll.py]
2014-08-01 Uncomment HW PWM code
2014-08-06 Cleanup code duplicated by merge, fix typo
    [backend.py, enroll.py]
2014-08-06 Use wiringpi2 for all GPIO functions
2014-08-06 Use wiringpi2 for all GPIO functions
    Conflicts:
    rpi.py
2014-08-07 filter by status
2014-08-07 Fix pin numbers
2014-08-08 Improve enroll.py, fix bug in backend.py -more standard prompts for enroll.py -fix bug in updateUser() in backend.py
    [backend.py, enroll.py]
2014-08-10 Remove old enroll.py, fix mistakenly added file
    [enroll.py]
2014-08-10 Combine add_user and get_user, bug fixes
    [database_cli.py, edit_user.py, get_user.py]
2014-08-10 Add checking for valid log types, fix a couple bugs in door-lock.py
    [backend.py, database_cli.py, door-lock.py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]
2014-08-11 Fix a couple bugs in interactive prompts
    [database_cli.py, edit_user.py, enroll.py]
2014-08-11 Fixed variable scope error in door-lock.py
    [enroll.py]
2014-08-11 Fix CLI history, tweak some prompts, remove some absolute filepaths, exit cleanly from cli on ctrl^c
    [database_cli.py, door-lock.py, enroll.py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]
2014-08-11 Improve CLI functionality -add ability to delete user info from CLI -fix header info in various files -fix history bug in cli output helper -add exit function to CLI -tweak output prompts -simplify g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
    [backend.py, database_cli.py, door-lock.py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]
2014-08-11 Add more colors to CLI output, fix cli bug
    [cli_helper.py, edit_user.py, enroll.py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]
2014-08-11 Fix issue with history and colored prompt
    [database_cli.py]
2014-08-11 Fix bug in backend.py getUser, add more input verification to CLI
    [backend.py, database_cli.py, enroll.py]
2014-08-12 Bug fixes, move python files to seperate folder
    [backend.py, cli_helper.py, database_cli.py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]
2014-08-13 Fix minor bugs and re-write filter processor in show_user
    [database_cli.py, edit_user.py, enroll.py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]
2014-08-13 Add filtering to backend.py getLogs, add command line arguments to all scripts
2014-08-13 Fix some issues with cli interface
    [backend.py, database_cli.py, edit_user.py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]
2014-08-19 Fix bug in add_user
    [edit_user.py]
2014-08-20 Fix missing import, make RC522 poll time closer to PN532
    [door-lock.py, rpi.py]
2014-08-20 Fix 2 bugs in enroll.py
    [edit_user.py, enroll.py]
2014-09-04 Fix code to work with new hardware
    [rpi.py]
2014-09-26 create shell script to add cron job, fix light behavior when enrolling
    [enroll.py]
2014-09-26 fix delay in reading door status -checking for NFC cards now only polls once, then returns -door status can be checked much more frequently other -change logging config to use dictionary/YAML file -r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
    [door-lock.py, rpi.py]
2014-09-27 fix enroll.py to work better with new nfc-read -enroll now loops 30 times to give time to swipe card -light flashes with every read (shows that enroll is running, not door-lock) -re-added logging to 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
    [door-lock.py, enroll.py]
2014-11-04 remove API key; don't de-activate leasor
2015-04-07 add interrupt for door arm button
2015-04-07 add more (non-working) interrupt code, add arm button via door-polling code
2015-04-07 fix LED blink is dumb
    [door-lock.py]
2015-04-30 set 100% duty cycle on buzzer
    [rpi.py]
2015-07-22 Add LCD arduino code
2015-10-08 Add Tom's 9-2015 schematic
    [reader-and-latch-client-schematic.sch]
2015-10-08 Add Tom's 13-2015 schematic
    [reader-and-latch-client-schematic.sch]
2015-10-10 Update from 9-2015
    [reader-and-latch-client-schematic.sch]
2015-11-10 Updating the displayed "Member since" date filter.
2015-11-11 Fix bug rs485 module bug, delete workaround code
    [driver.ino, reader.cpp, rs485.cpp]
2015-11-12 Reduce excess code -remove old test code -fix minor serial bug -clean up some formatting
    [driver.ino, reader.cpp, rs485.cpp]
2015-11-15 Fix index rollover causing audio to repeat
    [driver.ino]
2015-11-17 Re-organize code -add function to send button / door states -add class for door strike -re-arrange serial code
2015-11-23 Remove SoftwareSerial dependency - move to hardware serial port - fix error in byte stuffing algorithm - modify serial test code
    [driver.ino, rs485.cpp]
2015-11-24 fix minor serial debug bug
    [rs485.cpp]
2015-11-24 Modify audio code, fix serial bugs -restructure audio to take byte arrays -tunes can now be sent over network -bug preventing serial rx fixed
    [driver.ino, rs485.cpp]
2015-11-24 Fix audio and serial issues -fix bug causing packets to be processed twice -add more packet verification -fix wrong note being played sometimes
    [driver.ino, rs485.cpp]
2016-01-13 Update latch pin number
2016-01-24 fix plugin enable/disable buttons
2016-01-24 don't die when alarm decoder fails to connect
2016-01-25 Fix bug causing strike to stay at full power when unlocked indefinitely
    [strike.cpp]
2016-01-25 add GPIO toggle pin for R/W driver
2016-01-25 Fix serial bugs -packets were found invalid due to incorrectly pulling (fake) crc from packet -fixed sending NAK on packets not addressed to device -added more logging
    [driver.ino]
2016-01-27 Fix failure to go into WAIT_SEND after reading an NFC card
    [driver.ino]
2016-01-27 remove / from R/W Pin setting
2016-02-17 Add debugging to various files, fix bug in CRC calculation for escaped packets
    [rs485.cpp]
2016-02-17 re-add driver.ino
2016-03-02 Fix crash caused by verifying CRC
    [driver.ino]
2016-03-09 Add handling of deny message, fix minor logging bugs
    [driver.ino, rs485.cpp]
2016-03-09 Fix resend interval, remove old code
    [driver.ino]
2016-03-23 add missing break statement
    [driver.ino, rs485.cpp]
2016-03-26 fix bug sending UIDs of less than 7 bytes
    [driver.ino, reader.cpp]
2016-03-30 Update pin assignments, add serial LCD code
2016-03-30 flip pin even if there's an error
2016-04-02 Detect NFC reader failures, improve logging
    [driver.ino, reader.cpp, rs485.cpp]
2016-04-04 serialPort.write is not chainable
2016-04-06 fix plugin action button appearance
2016-04-06 center plugin enable/disable buttons
2016-05-01 fix serial boo-boos - don't wait for response on ACKs and resend the last non-ACK packet. Oops. - properly increment transaction ID when sending new packets
    [driver.ino]
2016-05-12 Fix serial issues, add conditionals for different modules -fix transaction ID not incrementing properly on received packets -improve collision detection and avoidance
    [driver.ino, rs485.cpp, strike.cpp]
2016-06-01 don't die on no credentials
2016-07-06 Fix some corner cases -re-lock door if program crashes -change start tune to 2 beeps -update lights, lock , and speaker even if uninitialized -add longer uid resend interval when the same id is scann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
    [driver.ino, reader.cpp, rs485.cpp]
2016-07-07 Fix same ID resend timeout
    [driver.ino]
2016-07-13 switch to broadcasts; fix LCD idle timer
2016-07-14 Fix client handling of broadcast packets
    [driver.ino]
2016-07-16 Add makefile for driver source, restructure source and libs
2016-07-16 Re-organize and update board layout files
    [Door_Client.brd, Door_Client.sch, makeict-security-server-V2016-3-29.brd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]
2016-07-17 better button grouping
2016-07-17 missed square brackets - not sure if this caused any problems
2016-07-19 Fix handling of client address initialization
    [driver.ino]
2016-07-19 Fix char* warning in lcd library
    [driver.ino]
2016-07-21 Move files back for Arduino IDE compatibility :(
2016-07-23 Parts List as of July 2016
    Through together a rough parts list. Things are a little more costy that I had thught.... Tom
    [DoorProjectParts.ods]
2016-07-23 Eagle PC board files and mill files
    Current board files as of July 2016 Tom
    [reader-and-latch-client-V2016-7-5.brd, reader-and-latch-client-V2016-7-5.sch]
2016-07-23 Fix failure to use correct client address in response packets.
    [driver.ino, rs485.cpp]
2016-07-27 Add watchdog timer to prevent client freezes
    [driver.ino, rs485.cpp]
2016-07-28 conform reconnect actions on watchdog timer
2016-07-29 Add hard reset for NFC reader after 2 failed attempts to restart it -also initialize some variable and clean some formatting
    [driver.ino, reader.cpp]
2016-07-29 Add forced reset if reader cannot be recovered
    [driver.ino, reader.cpp]
2016-08-01 Modify reader failure detection and recovery
    [driver.ino, reader.cpp]
2016-08-01 Tweak reader reset code
    [reader.cpp]
2016-08-01 Improve reader failure reset logic
    [driver.ino]
2016-08-02 Read doorState at beginning to prevent false updates
    [driver.ino]
2016-08-03 Clean up some config errors, use EEPROM config for lights and sounds
    [driver.ino]
2016-08-03 Fix config save/load error, add configs for wait and error lights
    [driver.ino]
2016-08-04 re-add mistakenly removed light sequence when unlocking
    [driver.ino]
2016-08-04 Fix config save/load to get all of the proper values -load same address as save (duh) -fix saving of start tune -modify audio to work with new config
    [driver.ino]
2016-08-04 Move board milling files to proper folder
    [reader-and-latch-client-V2016-7-5.brd, reader-and-latch-client-V2016-7-5.sch]
2016-08-07 fix pin assignment for PN532
    [driver.ino, reader.cpp]
2016-08-24 tweak NFC read error detection
    [driver.ino]
2016-08-30 Trigger doorbell over serial
    [makeict-security-server-V2016-3-29.brd]
2016-12-07 change pin assignments
2017-01-01 make latch work when no door switch is present
2017-01-08 Fix missing return value in reader initialization. oops.
    [reader.cpp]
2017-01-11 minor code clean-up -resolve warnings -re-configure some pre-processor directives in reader.cpp
    [reader.cpp, rs485.cpp]
2017-01-11 fix some whitespace, minor re-formatting
    [driver.ino]
2017-01-16 update .gitignore, add new board files, put gcode files in new folder
    [Mini_Door_Client.brd, Mini_Door_Client.sch, Portable_Client-2.brd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]
2017-01-17 add client name to arm messaging
2017-01-19 New client board V0.1
    [Mini_Door_Client.brd, Portable_Client-2.brd, Portable_Client-2.sch]
2017-01-31 Move pin definitions to definitions.h, fix doorbell input declaration
    [definitions.h, driver.ino]
2017-02-01 Redefine pnis for new board layout
2017-02-01 modify platformio.ini for new board layout
2017-02-01 fix a few board errors -MOSI and MISO swapped on LCD and SPI headers -change esp8266 capacitor to surface mount
    [Portable_Client-2.brd, Portable_Client-2.sch]
2017-02-07 Fix DRC errors in wifi client board.
    [Portable_Client-2.brd]
2017-02-08 re-assign pins for original board layout
2017-02-08 revert clock speed to 16mhz for original board layout
2017-02-08 actually revert pin assignments and clock speed this time
    [definitions.h]
2017-02-08 fix pin name
2017-02-09 change mini light board outline to mill layer
    [Door_Client.brd, Mini_Door_Client.brd]
2017-02-26 fix wdt boot loop
    [driver.ino]
2017-06-25 add basic log filtering -add filtering to backend api -add buttons in frontend -this code is probably awful
2018-04-09 Add support to UpSync™ user groups to WildApricot
2018-04-12 Add DownSync™ support
2019-03-02 fix nfc key assignment filter
2019-03-02 fix log filtering
2019-03-02 make filters into text inputs
2019-03-02 make filter strings ignore case
2019-03-03 add page increment and decrement buttons
2019-03-03 add ui for filtering by message
2019-03-03 re-organize code to build SQL query for log filters
2019-03-03 fix bug in log filter creation loop

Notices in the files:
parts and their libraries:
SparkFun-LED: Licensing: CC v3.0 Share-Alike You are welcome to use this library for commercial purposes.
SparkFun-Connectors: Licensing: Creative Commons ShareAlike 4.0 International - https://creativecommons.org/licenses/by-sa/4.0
